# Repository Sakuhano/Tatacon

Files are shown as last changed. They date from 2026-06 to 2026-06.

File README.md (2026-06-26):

# What is a Tatacon?
A Tatacon is a controller that uses a drum and drumsticks as its input mechanism, its most commonly used for the hit Japanese arcade video game: Taiko No Tatsujin.
A tatacon usually consists of 2 main parts, a drum and an ebox. The drum is self explanatory, you hit it to make inputs on piezo sensors attached to it. These signals are then sent to the EBox, which consists of a microcontroller and other components to improve processing speed and reduce misinput. The main feature I added that I've never seen on a commercially available ebox is a screen. The screen has a settings function allowing you to adjust the individual and total sensitivities of each piezo on the controller. It also consists of a controller (completely digital) which you can use to not require an external controller to navigate the Nintendo switch. Both the screen and controller functions are powered by 2 different boards so as not to lose any processing time for the inputs and make the most accurate controller. This github is just design, as the printed case is not complete, along with other polish I would like to add when finishing this project. 

All CAD was made in Tinkercad, I moved them to Onshape for sharing

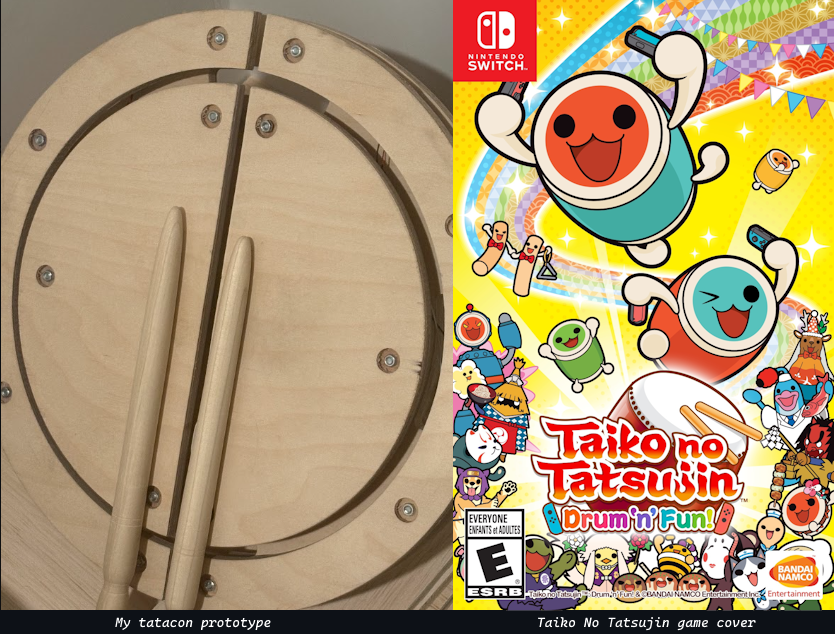
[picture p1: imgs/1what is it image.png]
Intro Screenshot


# Drum

I've split the section for the case and drum for ease of readability

## CAD and CNC

All the CNC machine files were based off openscad files by Moandor, these files are the standard shape used for almost all Tatacons, I made minimal edits for hole size (which turned out to be a mistake later however this was fixable with a drill)
I outsourced the CNC machine, and the woodshop generously offered the service at no-cost after hearing about my purpose. I then had to remove and sand each individual part from the large rectangle

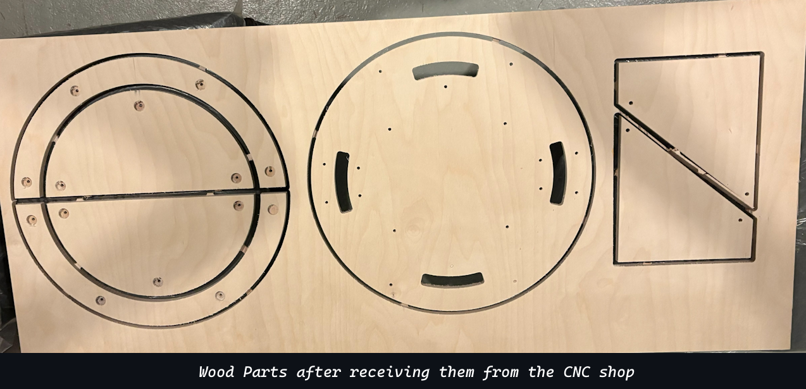
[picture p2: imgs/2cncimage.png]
CNC


Next, the CAD files were also based off the openscad files and were adapted for my specific size of wood and materials that I used.

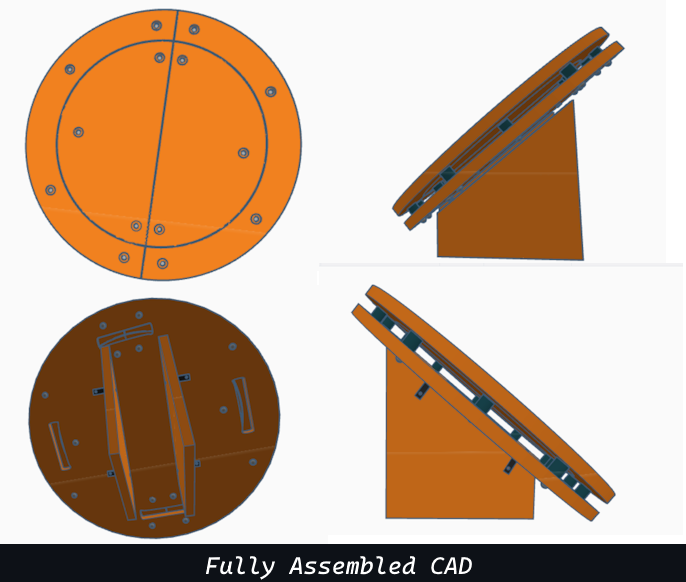
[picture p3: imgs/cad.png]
CAD


## Drumsticks

I made my own drumsticks as I have access to a lathe in school but it was made completely from scratch with no template, as such there is no design files for the drum stick. I just eyeballed them on the lathe. However, it is a replica of commonly available Taiko Bachi. Drumsticks are non-negotiable to use this product effectively.

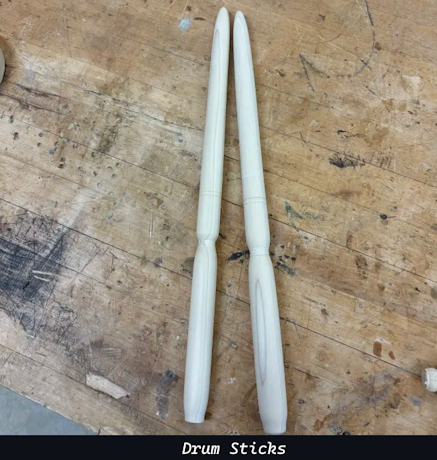
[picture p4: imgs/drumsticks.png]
DRMSTICK


## Drum Head (Skin)

Many projects like this buy official arcade skins imported from Japan, however those can range from 100-200 USD when factoring shipping. Due to this, I researched materials and found an effective substitute to be neoprene rubber. So using a strip and a large sheet, I constructed a drum head using superglue to bond the rubber. However, one issue is that the neoprene rubber releases a strong smell that fills a room, it can be mitigated by airing out the rubber however it still remains. Also, I use a towel over the head, as hitting the rubber with drumsticks quite hard tends to stain the sticks. Overall though, it works as quite a suitable substitute.

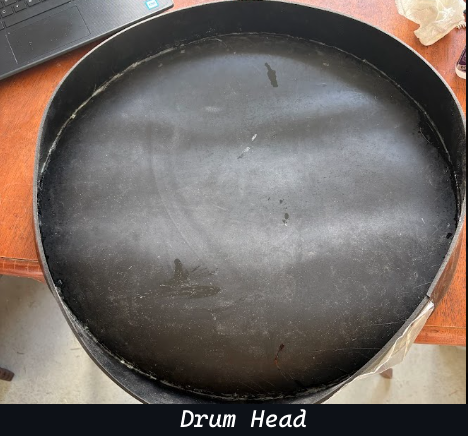
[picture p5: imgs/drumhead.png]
DRMHD


## Coding

To make the menu, I built off a lot of exisiting code, first I built a menu framework, basing it off code by upir, his code only had a menu framework and bitmap pixel art, however no features. I took his code and edited it to add my specific menus, run on a joystick for navigation as well as actually have features. The controller code is built off code from Luicat, which I took and allowed it to recieve inputs and changes from the menu. In these edits I allowed for serial communication between the boards so that one can interact with the other as well as actually send inputs to the Nintendo switch, making a successful digital controller and settings menu.

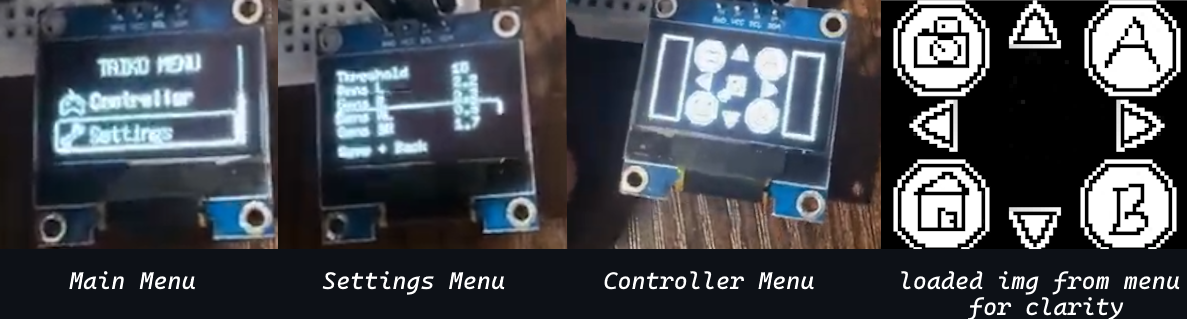
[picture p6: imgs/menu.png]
menus


## Pre Assembly

Before starting, there are a couple things to do to prepare. First it'll make life a lot easier if you solder extension wires on each piezo, however don't remove the wires that come preattached else you risk ruining the sensor. Then take each of these lengthened piezo sensors and electrical tape or glue them in the following locations to the top plate parts. There are successful labels on the 3d model, however they are difficult to see in this image.

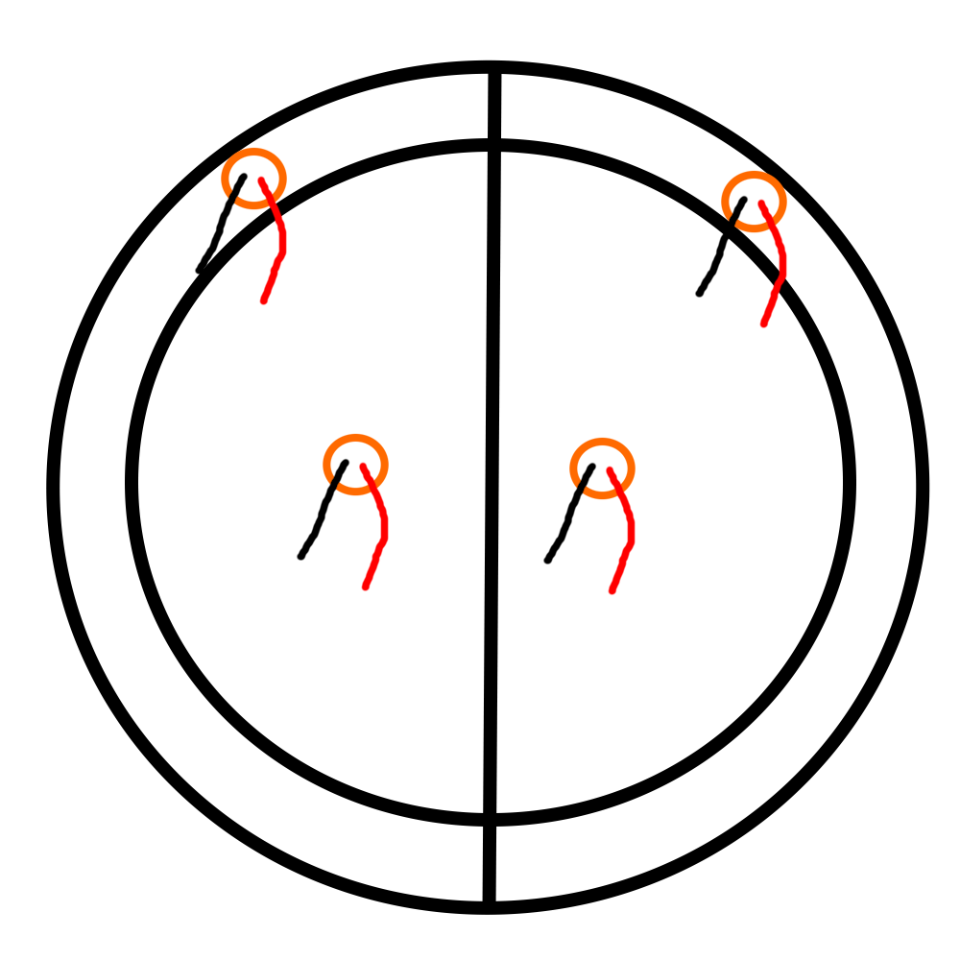
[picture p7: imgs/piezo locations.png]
piezos


## Drum Assembly

Assembly of this is quite easy once the parts are obtained, using the following items to hold things together
18x M5 bolts 
32x M5 thread nuts
46x washers (should be small and thin but size isn't super important)
soldering iron
electrical tape
piezos
wood pieces
corner brace
drill

Corner brace - note I included my specific one in the bom however, almost any can be used as I find it to be much better to just line up your support leg and measure where a hole using the brace has holes. This allows for much more part flexibility, and you just have to drill out the holes, and this is what I did for my brace.

To assemble, start with placing a washer on 14 of your M5 bolts, then take your bottom plate and place one of those 14 bolts in every single hole except for the 4 ones in the middle. it should look like this

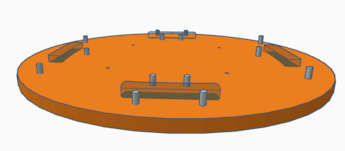
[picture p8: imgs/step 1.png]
Step 1


Now is the easiest time to place your support legs, Line up your corner brace(s) with your support legs and put a bolt through each of the 4 holes and add a nut on the opposite side from the bolt head and brace. Your supports shouldn’t move very much if at all.

Now, place a nut on each one of the bolts and screw it in fully, after this place each of your rubber dampers on the bolts and screw them in. now it should look something like this (support bolts not shown) , I've added a cross section of how it should look for each bolt

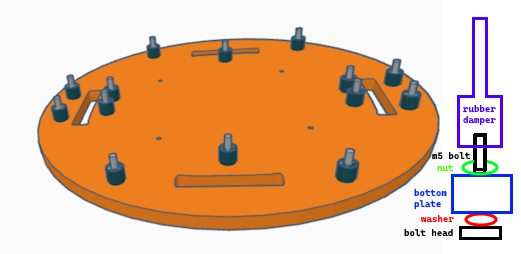
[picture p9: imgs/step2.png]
Step 2


Now place another washer on each, and place on each piece of the top plate, its easiest to thread the piezo wire extensions through the holes in the bottom plate now, then to finish off with adding a nut and tightening each bolt in fully. The image below is unfinished to make it easier to see. however the diagram on the right is complete

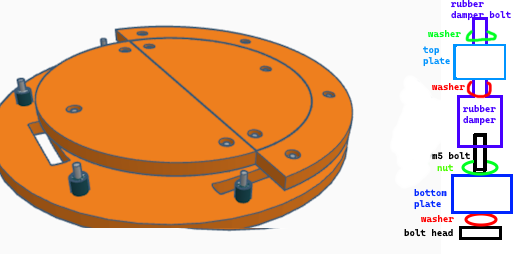
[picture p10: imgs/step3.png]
Step 3


Plug in your connectors attached to the piezo wires and you're good to go!

# Case/ebox
Originally, this was going to be a PCB, however after much research I thought making a case on the side to hold all my electronics would be much better. I've always liked how sim racing setups feel like stations rather than just accessories to the pc, I wanted the same vibe with this and with a large case on the side, it feels much more integrated into my gaming setup rather than being an accessory on the side. I'm a big fan of how it looks as well. 

## Code Flashing for Mega2560 R3

Take the leonardo code file and download all files inside. Open in arduino IDE and flash to the arduino mega2560 r3. 

## IDE preparation

Next follow the steps below, to use the code. These steps were taken from Luicats Github, as since my code is built off of his it requires this aswell
All credit goes to luicat for this, the required files are here: https://github.com/LuiCat/ArduinoTaikoController

### Modifications to Arduino IDE

Before starting Arduino IDE, to enable nintendo switch functionality, replace the following files with the ones provided in "setup" folder:

- `<your arduino installation path>/hardware/arduino/avr/libraries/HID/src/HID.h`
- `<your arduino installation path>/hardware/arduino/avr/libraries/HID/src/HID.cpp`

Then copy the text in board.txt in "setup" folder and append it to the following file:

- `<your arduino installation path>/hardware/arduino/avr/boards.txt`

If you've successfully done all the modifications above, you should be able to see the board called "Nintendo Switch Controller" next time you start Arduino IDE:

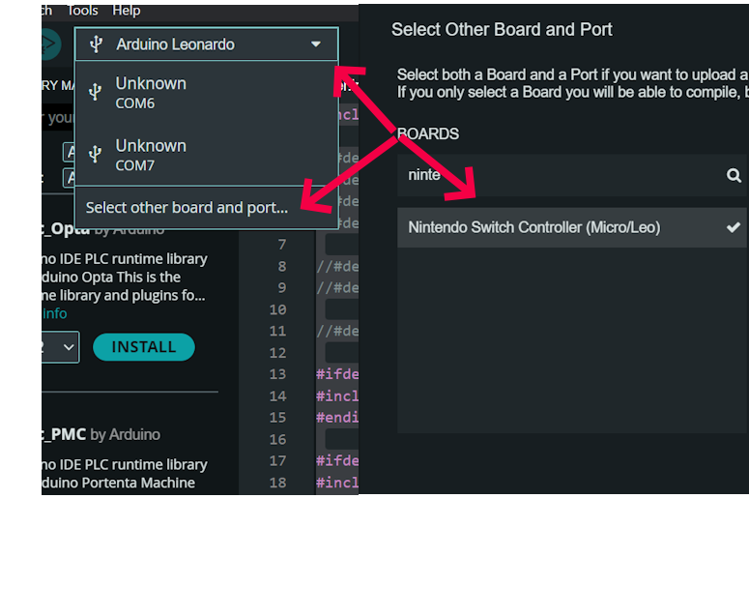
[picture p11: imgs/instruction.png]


Please select this board before uploading the code as this is essential for your Arduino Leonardo to be recognized by Nintendo Switch.

## Code Flashing for Leonardo

If the steps above have been followed you should be able to upload the code located in the leonardo code folder and just flash to the arduino.

## CAD

Using some part models I found online (credits in files) I added parts to my case to show what it would look like when fully done, below is the image, it has sections and text for easy assembly.

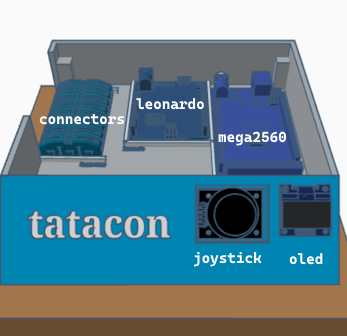
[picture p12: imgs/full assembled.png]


## Pre Assembly

Required materials:
Superglue
Neodymium Magnets
Plastic Screws and washers
Lever connectors
Arduinos
Ferrules
1m ohm resistor
dupont wires
db107 bridge rectifiers
soldering iron (optional)

First, after printing all the files, you want to take your magnets and glue them on the circle divots on the lid and the 4 lowered pillars in the case. 
Next, glue the joystick insert block on the case under the hole that corresponds with the joystick on the print. (check 3d file for reference). Take the Ferrules and place them on the wires coming out of the drum, differently colored in pairs so as to know which wire goes to which piezo.

## Base (optional)

requires
marker
drill
scrap wood
hammer

To add an extra element of flair you can make a base for your case, which makes it all the more cooler >:) this is totally optional though. To make one, you can use scrap wood and cut it to shape, then place your case over the wood in the spot you would like it to be. Mark the drill points by sticking a marker through the bolt holes for arduino. After drilling, hammer inserts into the holes. 

## Assembly

Now place all your components in their respective locations based on the image above as well as the labels placed on the board. Place your M3 bolts through the holes to lock all components into place. If you make a base, you can thread the bolts on the bottom through the m3 inserts Lock the components in with the washers. Glue 8 lever connectors in the spot that is labeled lever connector like the image above. Now you are ready to start wiring.

## Wiring

Wire everything according to the schematic below, its not necessary to use breadboards, as you can make your own splitter cables for ground by cutting dupont wires and soldering together. Go slow, and attach components to dupont wires for ease.

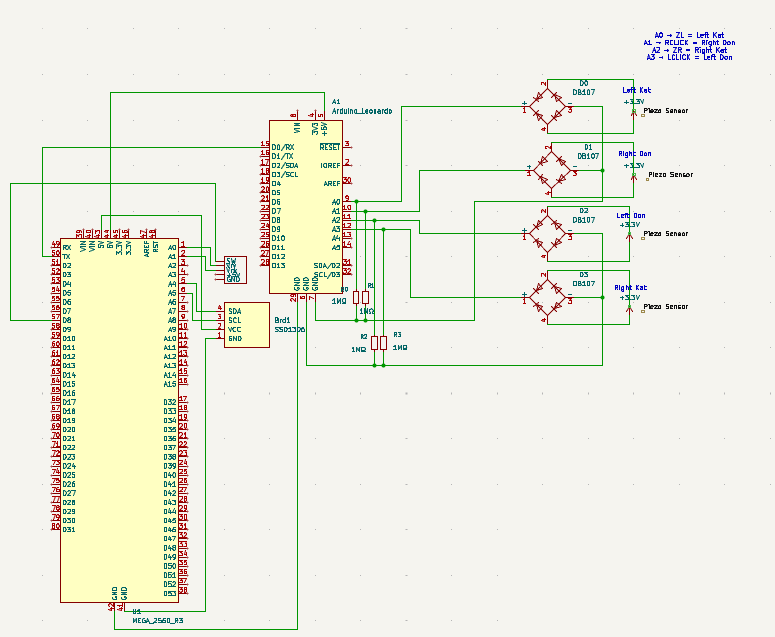
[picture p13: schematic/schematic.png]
schematic


After wiring everything together, plug the ferrules into the lever connects, close the lid and you're done!!!!

## Drumsticks

To make drumsticks I used a lathe and eyeballed some measurements using scrap wood for what I think the drumstick should be in thickness. However just searching up taiko no tatsujin bachi will help you find ones that work. Drumsticks are basically required for this as it makes much more precise inputs. However, I would more recommend just buying one if you don't have access or knowledge of using a lathe. They can go for as low as $10-$15 for a medium quality one.

## Why did I make this?

The idea for this project came to me when I saw an arcade game called Taiko No Tatsujin while abroad it uses a drum controller for inputs. I didn't give it much thought then, but when I got home. I really wanted to play it and found out there was an official controller available for purchase. It was called the Hori TaTacon. It cost about $70, so I was expecting a great product. But on first usage, I was disappointed. It required water bottles to keep it weighted so it didn't move, I had to hit it super hard for it to work and it was just janky. So I checked for alternatives online. I discovered numerous controllers available, however a decent one started at 200 for a small one and for a decent size one it went upwards of 500 or more. So I vowed to make my own. After doing some initial research over a year ago, I realized how much of a monumental task it was and gave up, but the want for one still lingered. And a year later, I found the motivation to start building again for Fallout. After many hours of work, that brings us to today.

## Acknowledgements

Luicat- provided the base controller code that was adapted
https://github.com/LuiCat/ArduinoTaikoController/tree/master

Newsham Woodshop in Aldan, PA for CNC machining my parts for no charge

upir on youtube for the base menu code and tutorial for menu building
https://www.youtube.com/watch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

Friends for helping and teaching me many things

My shop teacher for showing me how to use a lathe

Hack Club for providing the environment to build this

The Taiko no Tatsujin community for help

ShikyC - providing some wiring ideas and examples
https://github.com/ShikyC/Taiko-Drum-Controller-Arduino

Moandor for providing the base OPENSCAD files which I used to make CNCable files, as well as providing advice throughout this
https://github.com/moandor-y/taiko-no-tatsujin-drum

W3 schools for teaching me C++

and many others whose guides and articles I couldn't have made this project w/o

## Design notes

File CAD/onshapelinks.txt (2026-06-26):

onshape links

3d printed case stuff

case
https://cad.onshape.com/documents/54dbb6b467c79c1481cc51de/w/5ec1adc9ed4e6661e792b163/e/bbd9e8acfc5e05910346c073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

Joystick insert
https://cad.onshape.com/documents/fc0ff1775dbdd76d4b20aab2/w/3f028f6ef009c41b3ea4007a/e/76cd7d365b7bf1416ffd710e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

Lid
https://cad.onshape.com/documents/6eaeb32aaf644f3d68cbf503/w/1fe0b5226ccee433d61931fe

Drum Stuff 

full assembly
https://cad.onshape.com/documents/6aa020499e75e96b8eab69cc/w/65e557bf736931ccdf71789f/e/7f443d107fafc4eb4d13e204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

bottom plate
https://cad.onshape.com/documents/5576ca21738566e46db9488e/w/b4ec46c4cae221fd3d29429c/e/b8eab56c353da4d986eb8e67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

top plate inner circle half
https://cad.onshape.com/documents/6264209f9e15e6e33e3cf490/w/dd913410a18abddd75f68543/e/ff4a2ef36fbf7f71db56f856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

support leg
https://cad.onshape.com/documents/7e614a525852048ec9de92d2/w/fed911fc8de4cd6d258964b2/e/2d5b902312cc1db795a5a91f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

top plate outer ring half
https://cad.onshape.com/documents/2df3e2ba2070d28b6593318c/w/c982a54ffb2537adba425b43/e/677e48d9d90873e2fb1c649c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

long bolt
https://cad.onshape.com/documents/17738391c73abc8096c0120d/w/c15a20b6220537c8a73fae4a/e/787f6475aaf72aa3ffb1c559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

rubber damper insert
https://cad.onshape.com/documents/448b3b28842744ff81a8ea0b/w/0eaa3f8bf5ad5d896434f28e/e/ecefa9449a19118261a841f0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 

corner brace
https://cad.onshape.com/documents/f9e7ee72179795a1bbf91ffd/w/2ac4c80fcbbf8c5b16998179/e/1854f41f0b95239626bb5d1a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

drum head
https://cad.onshape.com/documents/2fa7758bc2087f84153a06a8/w/3eaaae4af81a9f6b6b8e88fe/e/0eb41013a2c1b161fea842c8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

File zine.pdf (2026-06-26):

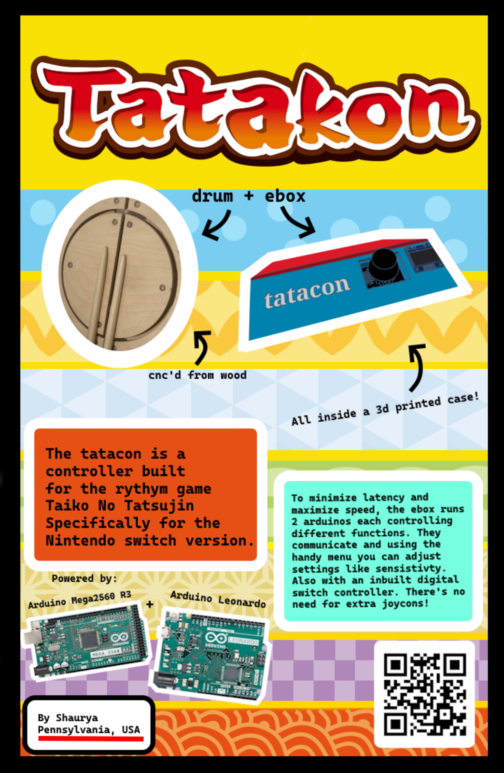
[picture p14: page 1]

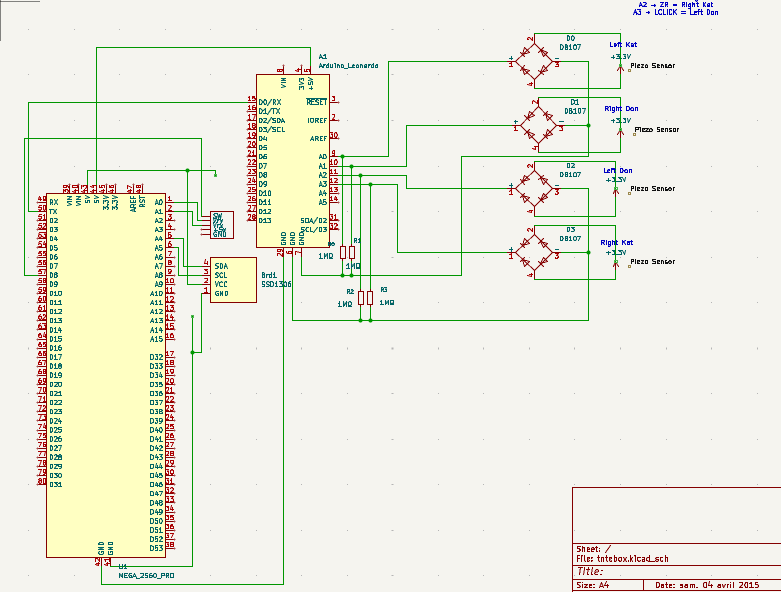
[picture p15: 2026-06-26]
imgs/Screenshot 2026-06-25 235739.png

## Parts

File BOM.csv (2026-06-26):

Item | Purpose | Source | Amount | Price | Subtotal | Total Spent (tax + shipping | Link
1/2 in. x 2 ft. x 4 ft. Sande Plywood | Material for the Drum | Home Depot | 1 | $27.26 |  |  | https://www.homedepot.com/p/ProWood-1-2-in-x-2-ft-x-4-ft-Sande-Plywood-Project-Panel-109068/202093791
Corner Brace | Joins stand of drum to drum pieces | Ace Hardware | 1 | $3.99 |  |  | https://www.acehardware.com/departments/hardware/angles-braces-and-brackets/braces/5021689
2mm x 6mm neodymium magnets | joins lid of case to case | Aliexpress | 1 | $4.63 |  |  | https://www.aliexpress.us/item/3256809168494688.html?mp=1&_randl_shipto=US
M5, 12mm vibration isolators | helps prevent other piezos from triggering when hitting the drum | AMAZON | 2 | $36.00 |  |  | https://www.amazon.com/dp/B07Z7GR4HW?ref=ppx_yo2ov_dt_b_fed_asin_title&th=1
Piezo Sensors (Guitar Pickups) | Houses the RP2040, connects to switch PCBs | Amazon | 1 | $6.99 |  |  | https://www.amazon.com/dp/B0DYNKK6B6?ref=ppx_yo2ov_dt_b_fed_asin_title
Assorted Nuts, Bolts, Washers | Joins everything together | Aliexpress | 1 | $14.97 |  |  | https://www.aliexpress.us/item/3256807011368573.html?mp=1
Neoprene Rubber Sheet 18x24" x 1/2'' | Sheet to cut drum head | Amazon | 1 | $34.19 |  |  | https://www.amazon.com/dp/B01CUQ51L4?ref=ppx_yo2ov_dt_b_fed_asin_title
Neoprene Rubber Ring 2" x 10' x 1/2' | Makes ring for drum head | Amazon | 1 | $12.00 |  |  | https://www.amazon.com/dp/B08LTJSTPT?ref=ppx_yo2ov_dt_b_fed_asin_title
Resistors 1MOHM | Used for the circut | Amazon | 1 | $4.99 |  |  | https://www.amazon.com/California-JOS-Tolerance-Resistor-Resistance/dp/B0BDKV4X96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
Jumper Cables | Used for the circut | Amazon | 1 | $6.98 |  |  | https://www.amazon.com/Elegoo-EL-CP-004-Multicolored-Breadboard-arduino/dp/B01EV70C78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
Arduino Leonardo | Used to control all components and circuts | Amazon | 1 | $23.80 |  |  | https://www.amazon.com/Arduino-org-A000057-Arduino-Leonardo-Headers/dp/B008A36R2Y?s=electronics
Lever Connectors | Used for the circut | Amazon | 1 | $4.99 |  |  | https://www.amazon.com/Electrical-Connectors-Assortment-Combination-Disconnect/dp/B0FLXBDNXM?s=industrial
Assorted Ferrules | attached to wires to connect them | Amazon | 1 | $4.99 |  |  | https://www.amazon.com/Terminals-Electrical-Connector-Insulated-Industrial/dp/B0FLX94V9H
Arduino Mega2560 R3 | Used to control the menu | Aliexpress | 1 | $3.99 |  |  | https://www.aliexpress.us/item/3256807774469671.html?curPageLogUid=RsXzqR9qEMZX
Elegoo White Filamente | Used as print mat | Amazon | 1 | $11.89 |  |  | https://www.amazon.com/ELEGOO-Filament-Dimensional-Accuracy-Compatible/dp/B0BM7WZPXJ
Assorted 22AWG wire | Used for connections | Amazon | 1 | $15.99 |  |  | https://www.amazon.com/TUOFENG-Hookup-Wires-6-Different-Colored/dp/B07TX6BX47?s=industrial
Electrical Tape | Sticking Piezos to wood and joining wires | Amazon | 1 | $2.98 |  |  | https://www.amazon.com/dp/B001AXD0EY?ref=ppx_yo2ov_dt_b_fed_asin_title&th=1
OLED Display SSD1306 | Used for menu system | Amazon | 1 | $9.99 |  |  | https://www.amazon.com/dp/B0FSRQG23K?ref=ppx_yo2ov_dt_b_fed_asin_title
Joystick | Used to control menu | Aliexpress | 1 | $5.78 |  |  | https://www.aliexpress.us/item/3256809168494688.html?mp=1&_randl_shipto=US
m3 wooden inserts | for inserting bolts into wood for case | Amazon | 1 | $5.79 |  |  | https://www.amazon.com/uxcell-Threaded-Stainless-Mechanical-Equipment/dp/B0DP2RYR2M
DB107 Bridge rectifier | used for better signal processing | Amazon | 1 | $5.99 |  |  | Tegg DB107 Bridge Rectifier 10PCS Electronic Silicon Diodes 1A 1000V 4-Pin Single Phase Diode Rectifier Bridge_AB: Amazon.com: Industrial & Scientific
Plastic bolts and nuts m3 | for attaching parts to the case | Amazon | 1 | $7.99 |  |  | https://www.amazon.com/QTEATAK-Plastic-Screws-Gasket-Assortment/dp/B0B17VVCMY
Hot Glue Gun | Used to apply hot glue | Owned | 1
Hot glue stick | Helps keep Piezos on wood | Owned | 1
Super Glue (Cyanoacrylate) | Helps join rubber ring to sheet | Owned | 1
Soldering Iron | Assembles the PCBs, can weld case to seal cracks | Owned | 1
Solder | Use with soldering iron for components | Owned | 1
Super Glue | Secures parts of the case to each other | Owned | 1
3d Printer | Used to print case | Owned | 1
CNC Mill | For Cutting Wood to shape | Outsourced (free) | 1
Sandpaper | For sanding wood | Owned | 1
Hand Saw | For cutting wood | Owned | 1
Wood Glue | For bonding wood | Owned | 1
Scrap Wood | Spare wood for base making | Owned | 1
Power Drill + bits | For drilling holes | Owned | 1
Marker | For marking points to drill | owned | 1
Hammer/mallet | For hammering in wooden inserts | Owned | 1
TOTAL COST USD |  |  |  |  | $256.17 | $271.54

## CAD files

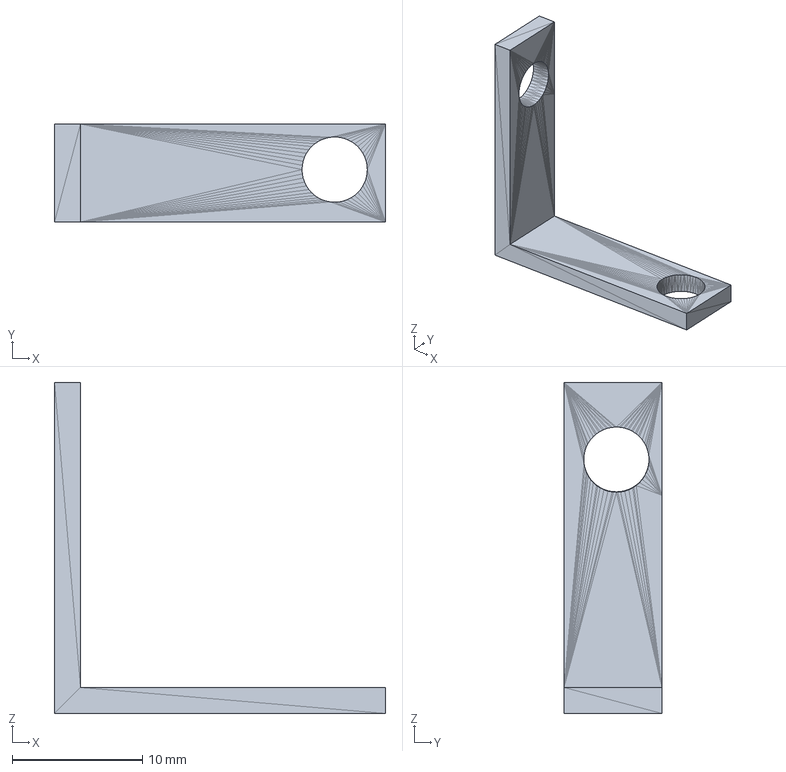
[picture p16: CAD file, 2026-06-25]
CAD/drum/assemblyparts/corner brace.step
25.4 x 7.52 x 25.4 mm

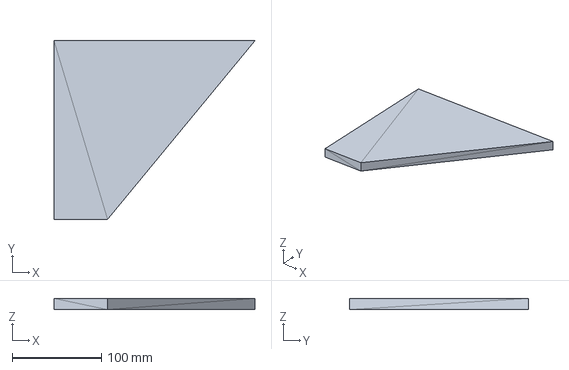
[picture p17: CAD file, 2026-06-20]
CAD/drum/bottom/support leg.step
225.0 x 200.0 x 12.7 mm

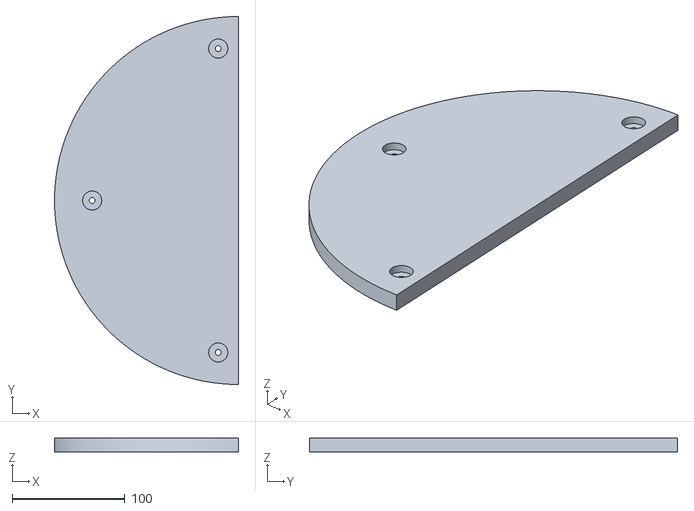
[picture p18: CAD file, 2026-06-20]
CAD/drum/top/top plate inner circle half.stl
163.5 x 327.0 x 12.7

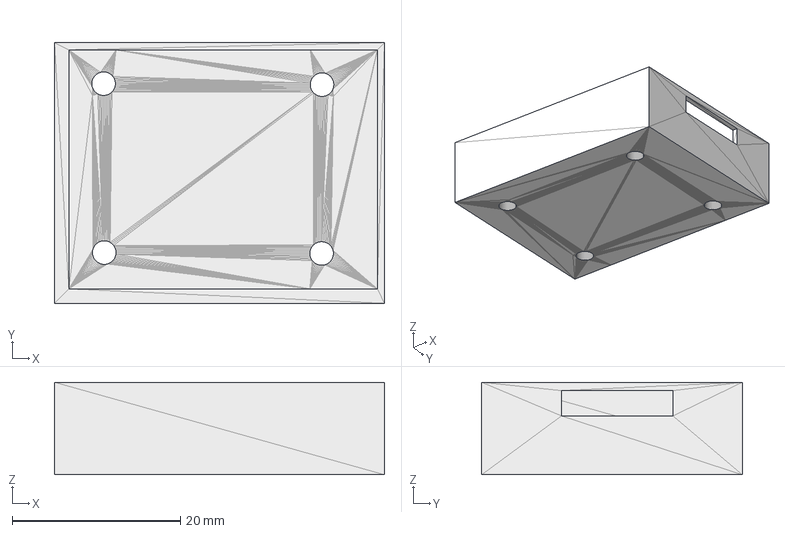
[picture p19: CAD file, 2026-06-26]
CAD/Case/joystick insert.step
39.2 x 31.0 x 11.0 mm

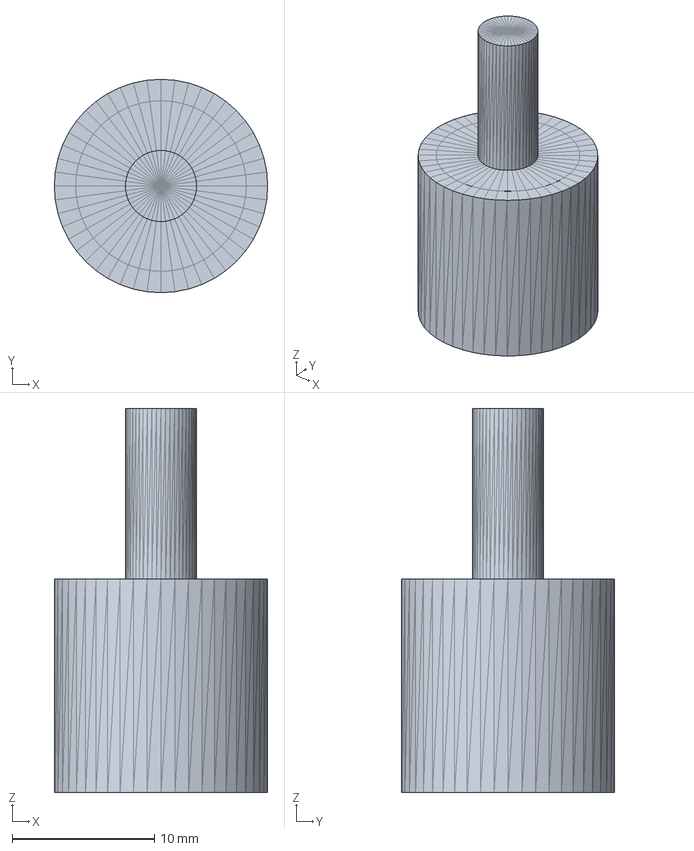
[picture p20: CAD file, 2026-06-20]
CAD/drum/assemblyparts/rubber insert.step
15.0 x 15.0 x 27.0 mm
STEP translator 7.5 1.1
STEP translator 7.5 1.2
STEP translator 7.5 1.3

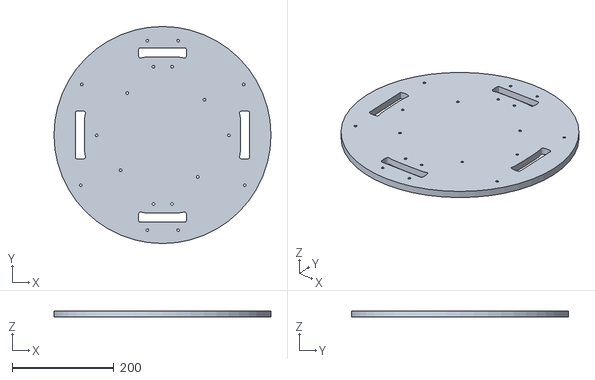
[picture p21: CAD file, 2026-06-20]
CAD/drum/bottom/bottom plate.stl
427.0 x 427.0 x 12.7

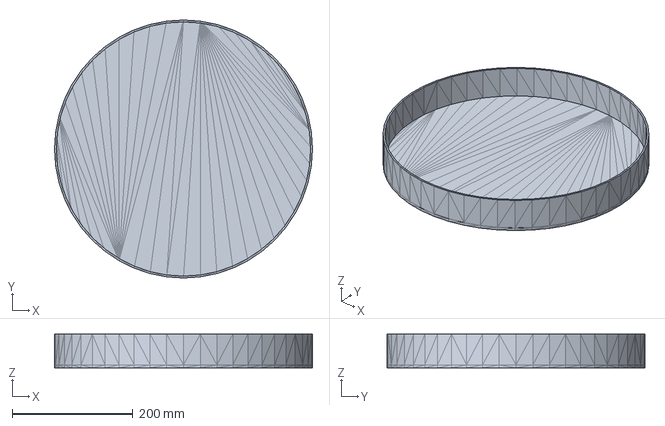
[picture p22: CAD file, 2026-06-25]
CAD/drum/drumhead.step
427.0 x 427.0 x 55.8 mm
STEP translator 7.5 1.1
STEP translator 7.5 1.2

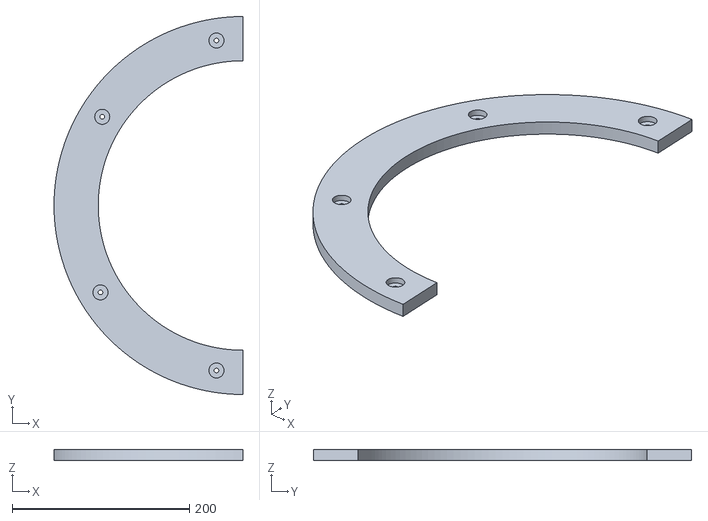
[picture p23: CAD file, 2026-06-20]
CAD/drum/top/top plate outer ring half.stl
213.5 x 427.0 x 12.7

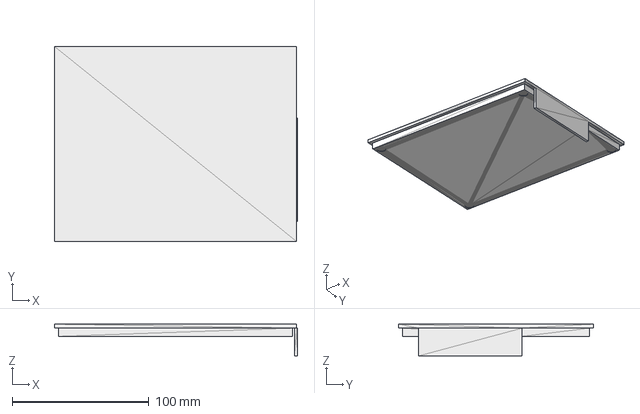
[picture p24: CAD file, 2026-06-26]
CAD/Case/roof.step
177.6 x 142.6 x 23.3 mm

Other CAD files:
CAD/drum/fully assembly.step
CAD/Case/case.step
CAD/drum/assemblyparts/long bolt.step
CAD/Case/case.stl
CAD/Case/joystick insert.stl
CAD/Case/roof.stl
CAD/drum/assemblyparts/corner brace.stl
CAD/drum/assemblyparts/long bolt.stl
CAD/drum/assemblyparts/rubber insert.stl
CAD/drum/bottom/support leg.stl
CAD/drum/drumhead.stl

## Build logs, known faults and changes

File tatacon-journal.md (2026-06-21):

# Tatacon — Journal Export

- Exported at: 2026-06-21T04:33:31Z
- Project ID: 2230
- Entries: 26

## Entry 1
- ID: 2982
- Author: shauryachutke
- Created At: 2026-04-19T23:28:44Z

### Content

Today, I worked on fixing issues and putting together my assembled parts of my Tatacon, my arduino code is very broken, but today I recieved all the parts from amazon. So i worked on testing, making a prototype and seeing what is wrong with my arduino code by testing on the actual videogame (hence the nintendo switch usage throughout the video) I managed to get it working for the first part but am currently having an issue where all piezos are sending the same output



101 minutes of work

### Recording Links

- https://www.youtube.com/watch?v=_0svMCqSPJo

## Entry 2
- ID: 3014
- Author: shauryachutke
- Created At: 2026-04-20T04:12:40Z

### Content

Today, I realized that my work yesterday was completely for naught, this made me a little sad, but it also gave me newfound motivation. You see, I realized I needed to change around my project quite a bit, yesterday was just a lot of hardware prototyping, fixing issues and general work for the actual controller with a lot of outside help, so much so that I realized this isn't my own project, infact im basically just following a tutorial no matter how much I change, regardless of what I do differently its basically the same general layout. So I realized I had to change things up a bit, instead of the making of the drum being my project, now I'm makiing my own custom EBOX, now you may ask. What the heck is an ebox? it sounds like a crappy knock off of a famous video game console. But it has nothing to do with that, an ebox for Taiko no tatsujin is what houses the electronics and circuitry for your actual taiko controller. Sounds simple enough right?, but its quite the opposite an ebox is the most integral component of your drum. They can be both simple and complex, it all depends on your code  you can add acessiories and all sorts of stuff, at its core its just the controller to send inputs to a drum but it can be so much more dpeending on what you do with it.
Today, I worked on doing some schematics, as its my first time doing kicad, so i was experimenting and learning with it while also modeling my prototype circuit. then I went into paint and modeled what i might want my PCB to look like.



### Recording Links

- https://lookout.hackclub.com/api/media/42abc607-094c-4bf3-9e1f-b150db092f2e/video.mp4

## Entry 3
- ID: 3156
- Author: shauryachutke
- Created At: 2026-04-21T04:01:38Z

### Content

Today was a lot of work on the base section of my drum, not the ebox. I finally got the parts I needed from amazon after ordering the wrong ones initiallty so my first drum was held up with tape, hopes, and dreams. But now I can finally use nuts and bolts >:). Except for the fact I forgot to get all the bolts I needed , so I know what I'm doing tommorow. Today was a bunch of building off of yesterday though, after going to the hardware store I bought some corner brackets so that was I could attach my supports to my actual backplate, however I did forget to record the corner bracket attachment and drilling which was a solid 45 minutes :(. Next I had to solder some of my piezos because over the weekend they broke, so I had to cut new wire that was actually long enough for my drum and didn't look like a complete mess, but I only had time for 2 before I had to go back to my class. So I'll continue that tommorow. Then after that was what I think the hardest part of today, making my drum head. I found no resources online on how to make my own, besides a material suggestion, so I decided to just wing it with the materials I had, I first cut out a rubber circle out of a large rubber sheet, I had to make my own compass tool to actually draw my circle too which took a while. Then cutting it was awful, it was really tough and I had to go quite slow, but I'm thankful I made no mistakes in that portion. Then I used superglue to glue my rubber strip around the circumference of my rubber circle, this was pretty bad and I think I breathed in too many superglue fumes, I also had to leave school midway and continue at home which kinda sucked because some of my strip kinda broke in the car ride home. But I got home and finished, this is the bad part though, I realized that by making my rubber circle bigger than my  backplate by about half an inch I had set myself up for failure. The rubber didn't fit snugly around the circle, meaning it was hard to attach and the rubber was also kinda of concaving into itself because it was originally rolled up. I'm still looking for a solution to this but for now I just added some strip on the inside to increase thickness. Then finally i went upstairs and put together my first prototype bywiring things things together, assembling the drum and 2 piezos annd testing on the game. 





### Recording Links

- https://lookout.hackclub.com/api/media/ccffe2c1-2404-4680-92b2-c149e2da0d29/video.mp4
- https://lookout.hackclub.com/api/media/3dda458f-5206-4c85-9353-068a0ff6e3a6/video.mp4
- https://lookout.hackclub.com/api/media/0b2eb833-0105-485f-adc3-582b54e839af/video.mp4
- https://lookout.hackclub.com/api/media/5d5f68c1-773c-4b8e-b661-58dd83a8d4fa/video.mp4
- https://lookout.hackclub.com/api/media/7d2a943c-879e-4513-b364-3fa3d0f45e43/video.mp4

## Entry 4
- ID: 3330
- Author: shauryachutke
- Created At: 2026-04-22T03:57:58Z

### Content

Overall, pretty decent day, I finally got some parts that I needed to finish the first prototype thst I tried yesterday. But after assembling and making a mess of wiring :( i made some mistakes so am trying to fix those however its working good. I thought raising my middle platforms would work well to offset the issues caused by the rubber head being to big but havent tried yet so  look out for that ig later today. I am proud that I was able to integrate the bridge capacitors I bought into a second breadboard I had and connected tomthe first so that way I could test the differences. 



### Recording Links

- https://lookout.hackclub.com/api/media/c13a05af-4416-48e3-889d-606fa0d4082d/video.mp4
- https://lookout.hackclub.com/api/media/f87230f3-f500-4840-a2d5-0550189cb48c/video.mp4

## Entry 5
- ID: 3340
- Author: shauryachutke
- Created At: 2026-04-22T05:00:45Z

### Content

Its a continuation of my other journal :D more than 3 hours done today, pretty proud of that. Besides that, the last 40 minutes were pretty cooked. I thought after assembling it was going to be easy breezy. It was not unfortunately "easy breezy". What followed after assembling was that it was partially working, 3/4 the buttons were sending inputs, 1 was sending the wrong input but overall I thought an easy fix. Then I looked at the wiring, then I got confused, there were no mistakes in wiring. Well, I thought there were but turns out I had it right all along (that did take up a lot of time though).I was extremely confused why 2 were sending the same input when connected to different inputs but oh well, my focus was on the part that sent no input. I thought I had a faulty piezo, but when exchanged same issue, I'm assuming its a sensitivity issue that I can adjust in code later but its quite annoying, secondly I somehow managed to stop all the buttons from working. So we started at about 50% succesful to 0% succesful, and it was 40 minutes of just frustration while listening to the same song on Taiko No tatsujin over and over, But such is the process of making something, it comes with good and it comes with bad and if I can't deal with failure or frustration or setback I'll never be able to make anything. Now, It's time to get my homework done. And I'm excited for a new tommorow.



### Recording Links

- https://lookout.hackclub.com/api/media/53ee500b-be87-4783-b174-0ac92afc0137/video.mp4
- https://lookout.hackclub.com/api/media/44baa002-443c-42e1-80e3-c0ae3a84ee1b/video.mp4

## Entry 6
- ID: 3497
- Author: shauryachutke
- Created At: 2026-04-23T03:34:00Z

### Content

After looking back through my schematics for some insights on how I could improve or fix my failing prototype, I came to the now obvious conclusion that it was impossible to look at. I could barely understand what was going on and it was pretty rough to look at. So I decided today to actually do a little Kicad research instead of going in completely blind and clean up my original schematic with labels and such. It's still a little messy and I don't understand a lot of stuff about Kicad. But, I'm overall pretty happy with how it turned out and I can't wait to start adapting this more my actual modifications and configurations I plan to add to make this project awesome :D. There's still a bunch I have to learn, but I'm definitely getting better and improving each day. I'm so excited to be part of hack club and can't wait for what else I do.


### Recording Links

- https://lookout.hackclub.com/api/media/263efa87-af05-4fab-9dff-b80a4bc98934/video.mp4
- https://lookout.hackclub.com/api/media/72e93248-44be-4fe7-a6b7-73067d9c52e0/video.mp4

## Entry 7
- ID: 3668
- Author: shauryachutke
- Created At: 2026-04-24T03:54:11Z

### Content

Today, quite the interesting day honestly. I didn't expect to get that much time in today and was planning on just trying to see what I did wrong in my build. However, after some careful thinking, I realized that the problems could be boiled down to a couple things. First, my sensitivity thresholds on my coding were too high, causing an input to not register, but then I thought about it further. Why the heck wasn't ANYTHING coming through the signal, no matter if I tapped the piezos directly or shuck the wood block it was attached to. I realized that it could also be a hardware issue, because my piezos looked likle they had been through 2 and a half wars. They were dirty, parts broken and overall just yikes. I assumed this didn't change much but I decided to give it a go on the multimeter and compare with some extra piezos I had recently ordered that I was hestiating on opening. Well the difference was SHOCKING to give a pun. The piezos I had been using barely got up to 1 volt max and that was only one. Most of them were capping around .5v or less. This was terrible, especially compared to the new ones which went up to 5 or 6 pretty easily. I knew that I had to make some changes, so I desoldered the wire on my other piezos, and at first I thought it would be good to directly attach them to the new piezos. However, that turned out to be a mistake, because it damaged the piezos and it became ineffective just like my other ones. So instead, I attached to the wires that were already soldered onto the piezos. I was having some trouble at first, both because my soldering iron was kinda crappy(broken tip), and my technique is pretty awful. But I realized that the broken shape of my iron was actually prefect for putting solder onto wires, and after that it all came out pretty well. It was a very long process, stripping wires with scissors and an exacto knife, wrapping, then hot gluing the solder pad on the piezo, and doing that 8 times took me a while. However, I'm very happy with how they turned out, and I can safely say that they look a lot better, so hopefully my problems are solved (Atleast hardware wise, and I can move on to tweaking the code and testing later tonight).



### Recording Links

- https://lookout.hackclub.com/api/media/729a4bf9-a3a2-48ff-89ab-94ec29e77307/video.mp4
- https://lookout.hackclub.com/api/media/ca6aeed5-0ada-4bb0-962c-d613f0298b58/video.mp4

## Entry 8
- ID: 3812
- Author: shauryachutke
- Created At: 2026-04-25T03:58:26Z

### Content

Yesterday during hardware testing, some of my piezos broke so I fixed them at school today as they have better soldering irons, and it was too late to set up my soldering stuff so I fixed it and made some backups in school today. When I got home, I wanted to fix the hardware issues from last night, (one of my inoputs was triggering randomly) so thats what I've been working on today. After changing the code base i was using i managed to get it somewhat working, not sure what the issue was though



### Recording Links

- https://lookout.hackclub.com/api/media/315d4cdf-79c5-45c9-81e3-faef4702b730/video.mp4
- https://lookout.hackclub.com/api/media/23c091d7-29ad-4b39-87d4-33272672aeee/video.mp4
- https://lookout.hackclub.com/api/media/0873297b-19f5-48ea-89d8-9550315f6bad/video.mp4

## Entry 9
- ID: 3994
- Author: shauryachutke
- Created At: 2026-04-26T03:57:55Z

### Content

Today I worked on C++, as I have no C++ skills to speak of and I want to be ready for Shenzen, as I have to learn to code for that. I also did more research on and  worked on my preliminary ebox design. My motivation to work on my drum has dipped a bit due to recent failure, and I'm writing this journal in advance of work as I don't wanna lose my streak. I've been out all day today and haven't had much to start but I'm basically planning out my schedule for the next hour rn. But i am starting to understand C++ a lot better which is really exciting!



### Recording Links

- https://lookout.hackclub.com/api/media/99682ca6-d3fb-4b64-9890-4fd37f135a32/video.mp4

## Entry 10
- ID: 4178
- Author: shauryachutke
- Created At: 2026-04-27T04:39:09Z

### Content

Today I'm working on continuing my W3 schools work, as well as working on shape for the first time, trying to learn and understand how to uses it to start my modeling, however I realized that I didn't understand it at all and I have forgotten all that I did in 7th grade with OnShape so I have to start relearning it from scratch. This is ok, and during my W3 schools work, I thought of a fun program I could make, and decided to start making it just as a little test to myself of what I've learned so far. It's just a thing that basically, it randomly adds or subtracts people from a room until a room has 6 people.



### Recording Links

- https://lookout.hackclub.com/api/media/4fc143d4-98a1-48f2-bbb4-cdaa89b319d0/video.mp4

## Entry 11
- ID: 4313
- Author: shauryachutke
- Created At: 2026-04-28T03:57:24Z

### Content

1. Today I'm gonna be continuing learning C++, as I feel I would be unprepared both for China, and making this project without having experience in C++. I made my first program yesterday, and I'm gonna be continuing with W3 Schools to try and get down the basics and everything else I might need for my project. I've also been looking into the parts I need and I'm gonna continue working on how the PCB would work,  as well as start to make my BOM for what I've done so far :D. Also I really don't understand the getline() function but its ok :D



### Recording Links

- https://lookout.hackclub.com/api/media/d57a67b7-0c9b-4069-9470-6e99870f6934/video.mp4

## Entry 12
- ID: 4438
- Author: shauryachutke
- Created At: 2026-04-29T03:37:57Z

### Content

Today, I was lowk locked and dialed for my project, I wanted to try to make up for my low time this weekend. Next week is finals week, so I'm super busy with studying and such. However, I'm trying my best to get work done and continue my streak. First, I worked on making a button input system that displays to an LCD. I literally have no idea how to do this, and I'm using my very  basic C++ experience and online guides to figure this out. This is an idea I'm experimenting with for my PCB, basically to count the hits , and statistics for each input of the controller, or add a menu like I saw in another controller online. Next, drumsticks but I'm lowk broke so I decided it would be good to use my schools lathe (which I have no experience with so I had to ask for some assistance from my teacher), using this I'm working on making some drumsticks, I've made most of one so far, and tomorrow I'm gonna start making the next one!



### Recording Links

- https://lookout.hackclub.com/api/media/93e37aa2-308a-4100-9f95-2dfb029f221f/video.mp4
- https://lookout.hackclub.com/api/media/1c564f4c-acf9-422a-959e-7456f8fd4bf9/video.mp4
- https://lookout.hackclub.com/api/media/c92b20ae-f7a7-46ef-a3ed-dcc13d37ea09/video.mp4
- https://lookout.hackclub.com/api/media/ce6bacd0-5a4f-421b-8d8c-826a86574fb5/video.mp4

## Entry 13
- ID: 4573
- Author: shauryachutke
- Created At: 2026-04-30T03:45:53Z

### Content

Today, I wasn't rexcording too much, as its hard to record while I'm moving and I like to move and walk around alot when I'm doing something like sanding (which is what I did today. But today, overall pretty chill. I finished my first drumstick which I'm very happy about, then I have to set up my second drum stick for the lathe tommorow, (which is what I'm gonna do). Then, after that I was pretty busy and out for most of the day, but I got home and I wanted to try working on my button input system for the LCD board. Basically, it jsut displays total of each hit and makes it easier for both debug and I want it as a feature on my final board I'm gonna put into kicad. But my lack of coding skills really holds me back, so I think I want to work on more W3 schools, cause I literally have to search up how to do everything, and my syntax still sucks butt. Anyways, I got a little frustrated and decided to start work on my BOM which actually looks pretty okay. I used my amazon list for prices and such. Tommorow, gonna do work on the lathe, maybe also make a cool laser design for the drumsticks!


!

### Recording Links

- https://lookout.hackclub.com/api/media/184b3480-5b6f-489c-9e20-35e204452392/video.mp4
- https://lookout.hackclub.com/api/media/44a9c510-590d-4342-bfc0-a7aa14a963f0/video.mp4

## Entry 14
- ID: 4713
- Author: shauryachutke
- Created At: 2026-05-01T03:56:41Z

### Content

Today, overall a pretty relaxing day. In school, I started making my second drumstick and overall it's turning out pretty okay. It's a little tough to match the dimensions and design to the other one but I'm doing my best and I think its coming out well. After I got home, I started working on my Zine page, I have a vision and just worked on one of the text elements in my poster for today.



### Recording Links

- https://lookout.hackclub.com/api/media/0ac6040e-be17-4c7a-9c68-acf11e7f9767/video.mp4
- https://lookout.hackclub.com/api/media/6fac2768-55d8-404b-880b-0b2f0c167f88/video.mp4
- https://lookout.hackclub.com/api/media/fe38342d-9061-4a0c-8e51-a30906f66285/video.mp4

## Entry 15
- ID: 4848
- Author: shauryachutke
- Created At: 2026-05-02T03:04:58Z

### Content

Ok, so while continuing to make my drumstick in school today. I accidentally closed a door to pick something up that was right in front of my video set up. Because of this, my recording of about 29 minutes named (failed timelapse) only has about 21 minutes of work shown even though I was working for the full 30. To make up for this I did, I did about 10-15 minutes of hardware work after I got home from school that I didn't add to the journal. I apologize, but I didn't want to lose my 20 or so min that were visible. Especially in my finals week where I don't have very much spare time :(. I also just did some zine work.



### Recording Links

- https://lookout.hackclub.com/api/media/e89f6350-cee5-47fc-a66b-533a123c117f/video.mp4
- https://lookout.hackclub.com/api/media/5e90f6a6-5c43-403d-897a-0ee9466edf54/video.mp4
- https://lookout.hackclub.com/api/media/95e120bd-d5b0-4ef0-9e65-5fefa86e3e80/video.mp4

## Entry 16
- ID: 4850
- Author: shauryachutke
- Created At: 2026-05-02T03:07:58Z

### Content

Accidentally added the wrong image to my last journal, so I changed it to the drumsticks I actually wanted to add

Screenshot 2026-04-30 235124.png

### Recording Links

- https://lookout.hackclub.com/api/media/f6740db4-2f11-4771-bdd4-9db022b55641/video.mp4

## Entry 17
- ID: 5213
- Author: shauryachutke
- Created At: 2026-05-03T03:45:18Z

### Content

Today, I did some more work on my zine page, and I realized I hated how it looked in canva, so I started from scratch in paint.net which I'm more familiar with.  I'm taking inspiration from the taiko no tatsujin rythym festival art page, and using elements from that in my design. It's coming along well so far, thought I've only added a couple small things. I think tommorow I might work on moddeling, kicad, w3schoools or just continue the ZINE. Overall, I'm happy with my progress so far but I'm a little worried about that 60 hour req as I feel like I'm close to done but also so far away.



### Recording Links

- https://lookout.hackclub.com/api/media/e40141b1-5cbe-4127-87ba-d9c4a6d98b49/video.mp4

## Entry 18
- ID: 5376
- Author: shauryachutke
- Created At: 2026-05-04T03:45:33Z

### Content

Honestly, not too much going on today and I considered not even posting a journal cause I was so locked into microeconomics (final EXAM TOMMOROW :( however I decided my zine page needed work, and i spent most of the time working on this one star pattern I wanted to add that I could NOT seem to get right, still unfinished but oh well thats for a different day
Screenshot 2026-05-03 234307.png

### Recording Links

- https://lookout.hackclub.com/api/media/37c62ac9-1540-4db2-9167-14de95476718/video.mp4

## Entry 19
- ID: 5547
- Author: shauryachutke
- Created At: 2026-05-05T03:58:21Z

### Content

Today, It was definitely a struggle to open up fallout and start recording, Normally I would be all over it but I have my Gov final tommorow so finding the justification to open up and record was a bit tough. However, I thought about what I worked on earlier that day, which was just trying to code and understand the extra features for my ebox. After about 15-20 minutes I forgot to record, I realized the code and syntax was hard for me to understnad in every regard so I decided today was a great day to finally lock back into w3 schools and catch up what I had been slacking on. Thats what I did, and it took me a while today and my progress def slowed as it took me longer to understand each part, I even had to consult the big GPT for one part. But overall, I got through it
Captura de pantalla 2026-05-05 055342.png

### Recording Links

- https://lookout.hackclub.com/api/media/f7ba3b4b-471c-416e-a4b7-5a0e9bae02d1/video.mp4

## Entry 20
- ID: 5836
- Author: shauryachutke
- Created At: 2026-05-07T03:36:01Z

### Content

Today, I worked on the LCD system for the board I want to design, however I ran into some problems. My main issue is that I have no idea what I'm doing wrong, in my code it should in theory display an output from 0-1023, with a 0 when the switch is closed and a 1023 when it's open. However both of my switches that are connected to the same circut output different things, and their value doesnt even change when I open and close the switch. I want to work more on it, but I have finals to lock in for :(. However, i think my work with C++ on W3 schools is amazing. I feel like I'm understanding more, and even the little I can do right now I don't think I would be able to without going through those tutorials.



### Recording Links

- https://lookout.hackclub.com/api/media/771dd657-4c72-4d2b-b10e-f1e71ad5e1f9/video.mp4

## Entry 21
- ID: 6033
- Author: shauryachutke
- Created At: 2026-05-08T03:52:16Z

### Content

Ok so I geniunely don't even know what to say. I didn't expect to make much progress, BUT I got my button mechanism actually working and I'm so happy. It's super wonkly, and I'm sure there's way better ways to do edge detection and this feels processor intensive but idc. I'll improve later I'm just happy to have progress!!!

Screenshot 2026-05-07 235041.png

### Recording Links

- https://lookout.hackclub.com/api/media/715819b2-d992-405d-b843-ea5ef8e0b2bd/video.mp4
- https://lookout.hackclub.com/api/media/757a9f24-9cc9-4414-9fc6-7bce6b48376d/video.mp4
- https://lookout.hackclub.com/api/media/15c71ec8-8c37-4a51-ba94-5183fb5ca590/video.mp4

## Entry 22
- ID: 6196
- Author: shauryachutke
- Created At: 2026-05-09T03:44:02Z

### Content

Today, I was a bit locked in ngl. After finishing a rudimentary version of edge detection yesterday, Today I wanted to work on the actual features that those kinds of things would be implemented into. Specifically, the menu features that go along with it. However, my lack of experience strikes again, as it took me like half the time to download the necessary programs. And the other half of time was spent trying to understand the menu example code that I still have no idea about.
Screenshot 2026-05-08 233912.png

### Recording Links

- https://lookout.hackclub.com/api/media/f1821b11-0cf9-4f31-8d8f-8a79acaf59eb/video.mp4

## Entry 23
- ID: 6373
- Author: shauryachutke
- Created At: 2026-05-10T03:38:55Z

### Content

Today, I worked on learning more about how to make the menu. It's so much more difficult than I expected and I took almost the whole time understanding the code. But now I think I'm startuing to get the hang of it. I tried writing some code at the end but it's still a little confusing just trying to learn as much as I can to do this.
Screenshot 2026-05-09 233515.png

### Recording Links

- https://lookout.hackclub.com/api/media/d45f24bc-2276-41d1-a2fe-5a7a093dcbb2/video.mp4

## Entry 24
- ID: 6708
- Author: shauryachutke
- Created At: 2026-05-12T03:55:20Z

### Content

So I started off designing my fritzing schematic for my circut, just prototyping my initial design to see what might work. But I realized something, my connector would be kinda cooked. So, I did some research about how similar products to what I'm trying to make do their connections. I came across the idea of a hexagon connector. I didn't see anything on the board, but it gave me the idea to go and design one I could use. So I hopped into tinkercad(rudimentary I know, I need to learn onshape). But I started making the preliminary design for that connector, and I also researched ideas of connecting my piezos wires to that connector in a way that would hold up. I think screw joints or something would be weird but I'll have to figure it out.
Screenshot 2026-05-11 235202.png

### Recording Links

- https://lookout.hackclub.com/api/media/7722c4c9-fb16-4f57-b0c0-e58f2c0ad1e7/video.mp4

## Entry 25
- ID: 6870
- Author: shauryachutke
- Created At: 2026-05-13T03:48:46Z

### Content

Today, I did some research and sent out an email to someone who had given me advice on my prototype drum. They've designed the specific component I need before and I asked for some advice about my specific circut. I'll do some prototype testing later, but I thought I would also just ask for expert advice. if I have it available. Then I worked on kicad and adding my specific parts I wanted into kicad. Adding onto my base circut, and learning how to wire a rotary encoder (still no idea) :(. I've recently only been doing 1 hour journals because of finals but after thursday I'll have the free time to journal more
Screenshot 2026-05-12 234832.png

### Recording Links

- https://lookout.hackclub.com/api/media/d715870b-0037-4363-9d05-57cd3cf8c481/video.mp4

## Entry 26
- ID: 15772
- Author: shauryachutke
- Created At: 2026-06-20T20:37:22Z

### Content

This is my longest journal yet because I just rushed through everything I had left to do. 

Lets go through it, first I started looking for options to make my menu and came across a nice video which detailed a style of menu i was interested in, this turned out to be a lifesaver because it was much easier to understand than the menu i was using before. This menu made life so much easier for me, I managed to figure out a ton of stuff quite quickly because the video also helped to explain everything. So using that video as a guide I  made a frame work of my menu, making pixel art and such for all the various sections (I really loved how it looked). Then I started coding the functionality for everything, I made an intiail scrollable menu based off the starting menu code. Then I thought it would be way easier to use a joystick for inputs instead of something like 3 buttons. So I switched my code over to a joystick based system. So after this, I made a library to control everyhing joystick based which allowed me to easily add functions I needed. Then I uploaaded this to the arduino library manager. because makes it easier to put into the emulator and make code edits while not on my current computer( this comes in handy later), Then afterwards, I worked on doing pixel art for the next section, the emulator controller. My friend offered me a suggestion for menu type, instead of a button selector and moving around the joystick, why not make a radial menu that you just have to pull the joystick in the direction of your input. And so, I switched my pixel art over to that, which was kind of torturous but oh well. I finished that code, then managed to finally get it working on my emulator woooo hoooo. The bitmaps were broken for a while but it all turned out okay so we ball, turns out the video mentioned the parameters for the drawing function wrong so I had it incorrect the whole time. Anyways, after fixing that, I realized time was running out, so I went back to my github page, and looked at what I needed. I went back to my initial phase of planning and saw what I did, so I made my CAD models, which were based off dxf files which were actually edits of files I found from someone online, now the reason I used the ones online is because after my research, that shape is the commonly used framework for all tatacons (drum controllers). So I could just base my CAD off these openscad files, while adding the dimensions and different parts I used. I also finished my bom using another bom as a template. Today, I have to go to 2 grad parties taking up my whole day, however after working throughout the night I still wasnt done, so I texted a friend and was able to arrange to work on his laptop, so I transferred my code over, and continued to work on it. I'm actually writing the journal from his house now, but I have to leave soon to go to the next party, where I'll continue to do work. I still have a bunch of coding and assembly to do. Hoping to god this all works out and I finish in time :(. Love you fallout, you taught me so much. This is probably my final journal b4 my submission. Peace out!
Screenshot 2026-06-20 163645.png

### Recording Links

- https://lookout.hackclub.com/api/media/3966dfbb-1aa1-4cf9-af7c-f294c0cd334d/video.mp4
- https://lookout.hackclub.com/api/media/3b7404c8-32a0-4b31-ac75-85a17a7b3553/video.mp4
- https://lookout.hackclub.com/api/media/7d155581-db5a-4806-b730-779e381ce028/video.mp4
- https://lookout.hackclub.com/api/media/8e34ece1-8696-404a-a1f6-df32bd877aba/video.mp4
- https://lookout.hackclub.com/api/media/870d5f5f-9dfb-45a1-8591-ca4ab7723179/video.mp4
- https://lookout.hackclub.com/api/media/3a7534f6-e0b2-45a0-b5e4-00b709a0c44b/video.mp4
- https://lookout.hackclub.com/api/media/7d7e07a4-8e51-40ac-894e-9bca3e5d8e35/video.mp4
- https://lookout.hackclub.com/api/media/85515103-cda3-4cb4-a03a-0e9a23bb4de9/video.mp4
- https://lookout.hackclub.com/api/media/fb9f17ee-8698-4a79-9f01-0502368a61d8/video.mp4

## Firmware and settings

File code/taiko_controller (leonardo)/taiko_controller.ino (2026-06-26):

#include "AnalogReadNow.h"

#define ENABLE_NS_JOYSTICK

#ifdef ENABLE_KEYBOARD
#include <Keyboard.h>
#endif

#ifdef ENABLE_NS_JOYSTICK
#include "Joystick.h"
const int led_pin[4] = {8, 9, 10, 11};
const int sensor_button[4] = {SWITCH_BTN_ZL, SWITCH_BTN_LCLICK, SWITCH_BTN_RCLICK, SWITCH_BTN_ZR};
#endif

#ifdef HAS_BUTTONS
int button_state[16] = {0, 0, 0, 0, 0, 0, 0, 0, 0, 0, 0, 0, 0, 0, 0, 0};
int button_cd[16] = {0, 0, 0, 0, 0, 0, 0, 0, 0, 0, 0, 0, 0, 0, 0, 0};
#ifdef ENABLE_KEYBOARD
const int button_key[16] = {
  KEY_UP_ARROW, KEY_RIGHT_ARROW, KEY_DOWN_ARROW, KEY_LEFT_ARROW,
  'k', 'j', 'f', 'd',
  KEY_PAGE_DOWN, KEY_PAGE_UP, KEY_ESC, ' ',
  KEY_F1, 'q', 0 , 0
};
#endif
#ifdef ENABLE_NS_JOYSTICK
const int button[16] = {
  0 , 0 , 0 , 0 ,
  SWITCH_BTN_X, SWITCH_BTN_A, SWITCH_BTN_B, SWITCH_BTN_Y,
  SWITCH_BTN_L, SWITCH_BTN_R, SWITCH_BTN_SELECT, SWITCH_BTN_START,
  SWITCH_BTN_CAPTURE, SWITCH_BTN_HOME, 0 , 0
};
const int hat_mapping[16] = {
  SWITCH_HAT_CENTER, SWITCH_HAT_U, SWITCH_HAT_R, SWITCH_HAT_UR,
  SWITCH_HAT_D, SWITCH_HAT_CENTER, SWITCH_HAT_DR, SWITCH_HAT_R,
  SWITCH_HAT_L, SWITCH_HAT_UL, SWITCH_HAT_CENTER, SWITCH_HAT_U,
  SWITCH_HAT_DL, SWITCH_HAT_L, SWITCH_HAT_D, SWITCH_HAT_CENTER,
};
#endif
#endif

int min_threshold = 15;
float sens[4] = {1.0, 1.0, 1.0, 1.0};

const long cd_length = 10000;
const float k_threshold = 1.5;
const float k_decay = 0.97;

const int pin[4] = {A0, A3, A1, A2};
const int key[4] = {'d', 'f', 'j', 'k'};

const int key_next[4] = {3, 2, 0, 1};

const long cd_stageselect = 200000;

bool stageselect = false;
bool stageresult = false;

float threshold = 20;
int raw[4] = {0, 0, 0, 0};
float level[4] = {0, 0, 0, 0};
long cd[4] = {0, 0, 0, 0};
bool down[4] = {false, false, false, false};
#ifdef ENABLE_NS_JOYSTICK
uint8_t down_count[4] = {0, 0, 0, 0};
#endif

typedef unsigned long time_t;
time_t t0 = 0;
time_t dt = 0, sdt = 0;

void sample() {
  int prev[4] = {raw[0], raw[1], raw[2], raw[3]};
  raw[0] = analogRead(pin[0]);
  raw[1] = analogRead(pin[1]);
  raw[2] = analogRead(pin[2]);
  raw[3] = analogRead(pin[3]);
  for (int i=0; i<4; ++i)
    level[i] = abs(raw[i] - prev[i]) * sens[i];
}

void sampleSingle(int i) {
  int prev = raw[i];
  raw[i] = analogReadNow();
  level[i] = abs(raw[i] - prev) * sens[i];
  analogSwitchPin(pin[key_next[i]]);
}

void setup() {
  analogReference(DEFAULT);
  analogSwitchPin(pin[0]);
  pinMode(LED_BUILTIN, OUTPUT);
  digitalWrite(LED_BUILTIN, LOW);
#ifdef ENABLE_NS_JOYSTICK
  for (int i = 0; i < 8; ++i) pinMode(i, INPUT_PULLUP);
  for (int i = 0; i < 4; ++i) {  digitalWrite(led_pin[i], HIGH); pinMode(led_pin[i], OUTPUT); }
#endif
#ifdef ENABLE_KEYBOARD
  Keyboard.begin();
#endif
  t0 = micros();
  Serial.begin(9600);

  Serial1.begin(9600);
}

void parseSerial() {

  static char command = -1;
  if (Serial.available() > 0) {
    char c = Serial.read();
    if (command == -1)
      command = c;
    else {
      switch (command) {
      case 'C':
        Serial.write('C');
        Serial.write(c);
        Serial.flush();
        break;
      case 'S':
        stageselect = (c == '1');
        digitalWrite(LED_BUILTIN, stageselect ? HIGH : LOW);
        break;
      case 'R':
        stageresult = (c == '1');
        digitalWrite(LED_BUILTIN, stageresult ? HIGH : LOW);
        break;
      }
      command = -1;
    }
  }

  static char s1_command = -1;
  static int  s1_sens_idx = -1;

  while (Serial1.available() > 0) {
    char c = Serial1.read();

    if (s1_command == 'W' && s1_sens_idx == -1) {
      s1_sens_idx = (int)(unsigned char)c;
      continue;
    }

    if (s1_command == -1) {
      s1_command = c;
      continue;
    }

    switch (s1_command) {

      case 'V': {
        #ifdef ENABLE_NS_JOYSTICK
        switch (c) {
          case 'A': Joystick.Button |= SWITCH_BTN_A;       break;
          case 'B': Joystick.Button |= SWITCH_BTN_B;       break;
          case 'H': Joystick.Button |= SWITCH_BTN_HOME;    break;
          case 'C': Joystick.Button |= SWITCH_BTN_CAPTURE; break;
          case 'U': Joystick.HAT = SWITCH_HAT_U;           break;
          case 'D': Joystick.HAT = SWITCH_HAT_D;           break;
          case 'L': Joystick.HAT = SWITCH_HAT_L;           break;
          case 'R': Joystick.HAT = SWITCH_HAT_R;           break;
        }
        Joystick.sendState();
        delay(25);
        Joystick.Button = SWITCH_BTN_NONE;
        Joystick.HAT = SWITCH_HAT_CENTER;
        Joystick.sendState();
        #endif
        break;
      }

      case 'T': {

        int val = (int)(unsigned char)c;
        if (val >= 1 && val <= 255) min_threshold = val;
        break;
      }

      case 'W': {

        if (s1_sens_idx >= 0 && s1_sens_idx <= 3) {
          int val = (int)(unsigned char)c;
          if (val >= 1 && val <= 50) {
            sens[s1_sens_idx] = val / 10.0f;
          }
        }
        s1_sens_idx = -1;
        break;
      }
    }

    s1_command = -1;
  }
}

void loop_test() {
  sampleSingle(0);
  Serial.print(level[0]);
  Serial.print("\t");
  delayMicroseconds(500);
  sampleSingle(1);
  Serial.print(level[1]);
  Serial.print("\t");
  delayMicroseconds(500);
  sampleSingle(2);
  Serial.print(level[2]);
  Serial.print("\t");
  delayMicroseconds(500);
  sampleSingle(3);
  Serial.print(level[3]);
  Serial.println();
  delayMicroseconds(500);
}

void loop_test2() {
  Serial.print(analogRead(pin[0]));
  Serial.print("\t");
  delayMicroseconds(500);
  Serial.print(analogRead(pin[1]));
  Serial.print("\t");
  delayMicroseconds(500);
  Serial.print(analogRead(pin[2]));
  Serial.print("\t");
  delayMicroseconds(500);
  Serial.print(analogRead(pin[3]));
  Serial.println();
  delayMicroseconds(500);
}

void loop() {

  static int si = 0;

  parseSerial();

  time_t t1 = micros();
  dt = t1 - t0;
  sdt += dt;
  t0 = t1;

  float prev_level = level[si];
  sampleSingle(si);
  float new_level = level[si];
  level[si] = (level[si] + prev_level * 2) / 3;

  threshold *= k_decay;

  for (int i = 0; i != 4; ++i) {
    if (cd[i] > 0) {
      cd[i] -= dt;
      if (cd[i] <= 0) {
        cd[i] = 0;
        if (down[i]) {
#ifdef ENABLE_KEYBOARD
          Keyboard.release(stageresult ? KEY_ESC : key[i]);
#endif
          down[i] = false;
        }
      }
    }
  }

  int i_max = 0;
  int level_max = 0;

  for (int i = 0; i != 4; ++i) {
    if (level[i] > level_max && level[i] > threshold) {
      level_max = level[i];
      i_max = i;
    }
  }

  if (i_max == si && level_max >= min_threshold) {
    if (cd[i_max] == 0) {
      if (!down[i_max]) {
#ifdef DEBUG_DATA
        Serial.print(level[0], 1);
        Serial.print("\t");
        Serial.print(level[1], 1);
        Serial.print("\t");
        Serial.print(level[2], 1);
        Serial.print("\t");
        Serial.print(level[3], 1);
        Serial.print("\n");
#endif
#ifdef ENABLE_KEYBOARD
        if (stageresult) {
          Keyboard.press(KEY_ESC);
        } else {
          Keyboard.press(key[i_max]);
        }
#endif
        down[i_max] = true;
#ifdef ENABLE_NS_JOYSTICK
        if (down_count[i_max] <= 2) down_count[i_max] += 2;
#endif
      }
      for (int i = 0; i != 4; ++i)
        cd[i] = cd_length;
#ifdef ENABLE_KEYBOARD
      if (stageselect)
        cd[i_max] = cd_stageselect;
#endif
    }
    sdt = 0;
  }

  if (cd[i_max] > 0) {
    threshold = max(threshold, level_max * k_threshold);
  }

  static time_t ct = 0;
  static int cc = 0;
  ct += dt;
  cc += 1;

#ifdef HAS_BUTTONS
  static int bi = 3;
  pinMode(bi+4, INPUT_PULLUP);
  bi = ((bi+1)&3);
  pinMode(bi+4, OUTPUT);
  digitalWrite(bi+4, LOW);

  int state;
  int* bs = button_state + (bi << 2);
  int* bc = button_cd + (bi << 2);
  for (int i = 0; i < 4; ++i) {
    state = (digitalRead(i) == LOW);
    if (bc[i] != 0) {
      bc[i] -= ct;
      if (bc[i] < 0) bc[i] = 0;
    }
    if (state != bs[i] && bc[i] == 0) {
      bs[i] = state;
      bc[i] = 15000;
#ifdef ENABLE_KEYBOARD
      if (state) {
        Keyboard.press(button_key[(bi << 2) + i]);
      } else {
        Keyboard.release(button_key[(bi << 2) + i]);
      }
#endif
    }
#ifdef ENABLE_NS_JOYSTICK
    Joystick.Button |= (bs[i] ? button[(bi << 2) + i] : SWITCH_BTN_NONE);
#endif
  }
#endif

#ifdef ENABLE_NS_JOYSTICK
  if (ct > 32000 || (ct > 8000 && (down_count[0] || down_count[1] || down_count[2] || down_count[3]))) {
    for (int i = 0; i < 4; ++i) {
      bool state = (down_count[i] & 1);
      Joystick.Button |= (state ? sensor_button[i] : SWITCH_BTN_NONE);
      down_count[i] -= !!down_count[i];
      digitalWrite(led_pin[i], state ? LOW : HIGH);
    }
#ifdef HAS_BUTTONS
    state = 0;
    for (int i = 0; i < 4; ++i) {
      state |= (button_state[i] ? 1 << i : 0);
    }
    Joystick.HAT = hat_mapping[state];
#endif
    Joystick.sendState();
    Joystick.Button = SWITCH_BTN_NONE;
#ifdef DEBUG_TIME
    if (cc > 0)
      Serial.println((float)ct/cc);
#endif
    ct = 0;
    cc = 0;
  }
#endif

#ifdef DEBUG_OUTPUT
  static bool printing = false;
#ifdef DEBUG_OUTPUT_LIVE
  if (true)
#else
  if (printing || (threshold > 10))
#endif
  {
    printing = true;
    Serial.print(level[0], 1);
    Serial.print("\t");
    Serial.print(level[1], 1);
    Serial.print("\t");
    Serial.print(level[2], 1);
    Serial.print("\t");
    Serial.print(level[3], 1);
    Serial.print("\t| ");
    Serial.print(cd[0] == 0 ? "  " : down[0] ? "# " : "* ");
    Serial.print(cd[1] == 0 ? "  " : down[1] ? "# " : "* ");
    Serial.print(cd[2] == 0 ? "  " : down[2] ? "# " : "* ");
    Serial.print(cd[3] == 0 ? "  " : down[3] ? "# " : "* ");
    Serial.print("|\t");
    Serial.print(threshold, 1);
    Serial.println();
    if(threshold <= 5){
      Serial.println();
      printing = false;
    }
  }
#endif

  level[si] = new_level;
  si = key_next[si];

  long ddt = 300 - (micros() - t0);
  if(ddt > 3) delayMicroseconds(ddt);

}

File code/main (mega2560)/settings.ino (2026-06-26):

#include "U8glib.h"
#include "JoystickButton.h"
#include "bitmaps.h"
#include "EEPROM.h"

extern U8GLIB_SSD1306_128X64 u8g;
extern JoyButton joystick;
extern int current_screen;

#define SW_PIN 8

#define EEPROM_THRESH_ADDR  0
#define EEPROM_SENS0_ADDR   1
#define EEPROM_SENS1_ADDR   2
#define EEPROM_SENS2_ADDR   3
#define EEPROM_SENS3_ADDR   4

int threshold_value = (EEPROM.read(EEPROM_THRESH_ADDR) == 255) ? 15 : EEPROM.read(EEPROM_THRESH_ADDR);

int sens_val[4] = {
  (EEPROM.read(EEPROM_SENS0_ADDR) == 255) ? 10 : EEPROM.read(EEPROM_SENS0_ADDR),
  (EEPROM.read(EEPROM_SENS1_ADDR) == 255) ? 10 : EEPROM.read(EEPROM_SENS1_ADDR),
  (EEPROM.read(EEPROM_SENS2_ADDR) == 255) ? 10 : EEPROM.read(EEPROM_SENS2_ADDR),
  (EEPROM.read(EEPROM_SENS3_ADDR) == 255) ? 10 : EEPROM.read(EEPROM_SENS3_ADDR)
};

int settings_pos = 0;
#define SETTINGS_COUNT 6

bool showSavedPopup = false;
unsigned long popupStartTime = 0;

unsigned long lastInputTime = 0;
#define INPUT_DEBOUNCE_MS 200

void sendSettingsToController() {

  Serial1.write('T');
  Serial1.write((byte)threshold_value);

  for (int i = 0; i < 4; i++) {
    Serial1.write('W');
    Serial1.write((byte)i);
    Serial1.write((byte)sens_val[i]);
  }
}

void settingsMenu() {

    joystick.update();
    int x = joystick.readX();
    int y = joystick.readY();

    if (showSavedPopup) {
        if (millis() - popupStartTime > 700) {
            showSavedPopup = false;
            current_screen = 0;
        }
        return;
    }

    if (millis() - lastInputTime < INPUT_DEBOUNCE_MS) return;

    if (y >= 700) {
        settings_pos--;
        if (settings_pos < 0) settings_pos = 0;
        lastInputTime = millis();
    }
    else if (y <= 300) {
        settings_pos++;
        if (settings_pos >= SETTINGS_COUNT) settings_pos = SETTINGS_COUNT - 1;
        lastInputTime = millis();
    }

    if (settings_pos == 0) {
        if (x >= 700) { threshold_value++; lastInputTime = millis(); }
        if (x <= 300) { threshold_value--; lastInputTime = millis(); }
        if (threshold_value < 1) threshold_value = 1;
        if (threshold_value > 255) threshold_value = 255;
    }

    if (settings_pos >= 1 && settings_pos <= 4) {
        int idx = settings_pos - 1;
        if (x >= 700) { sens_val[idx]++; lastInputTime = millis(); }
        if (x <= 300) { sens_val[idx]--; lastInputTime = millis(); }
        if (sens_val[idx] < 1)  sens_val[idx] = 1;
        if (sens_val[idx] > 50) sens_val[idx] = 50;
    }

    if (settings_pos == 5) {
        if (digitalRead(SW_PIN) == LOW) {
            EEPROM.update(EEPROM_THRESH_ADDR, (byte)threshold_value);
            EEPROM.update(EEPROM_SENS0_ADDR, (byte)sens_val[0]);
            EEPROM.update(EEPROM_SENS1_ADDR, (byte)sens_val[1]);
            EEPROM.update(EEPROM_SENS2_ADDR, (byte)sens_val[2]);
            EEPROM.update(EEPROM_SENS3_ADDR, (byte)sens_val[3]);

            sendSettingsToController();

            showSavedPopup = true;
            popupStartTime = millis();
        }
    }
}

void drawSettingsMenu() {

    settingsMenu();

    if (showSavedPopup) {
        u8g.firstPage();
        do {
            u8g.setFont(u8g_font_6x10);
            u8g.drawStr(30, 32, "Saved + Sent!");
        } while (u8g.nextPage());
        return;
    }

    u8g.firstPage();
    do {

        if (settings_pos == 0) u8g.drawBitmapP(0, 0,  128/8, 10, bitmap_item_sel_outline);
        if (settings_pos == 1) u8g.drawBitmapP(0, 10, 128/8, 10, bitmap_item_sel_outline);
        if (settings_pos == 2) u8g.drawBitmapP(0, 20, 128/8, 10, bitmap_item_sel_outline);
        if (settings_pos == 3) u8g.drawBitmapP(0, 30, 128/8, 10, bitmap_item_sel_outline);
        if (settings_pos == 4) u8g.drawBitmapP(0, 40, 128/8, 10, bitmap_item_sel_outline);
        if (settings_pos == 5) u8g.drawBitmapP(0, 54, 128/8, 10, bitmap_item_sel_outline);

        u8g.setFont(u8g_font_6x10);

        u8g.drawStr(2, 9, "Threshold");
        u8g.drawStr(90, 9, String(threshold_value).c_str());

        char buf[6];
        const char* labels[4] = {"Sens L", "Sens R", "Sens DL", "Sens DR"};
        for (int i = 0; i < 4; i++) {
            u8g.drawStr(2, 9 + (i+1)*10, labels[i]);

            sprintf(buf, "%d.%d", sens_val[i]/10, sens_val[i]%10);
            u8g.drawStr(90, 9 + (i+1)*10, buf);
        }

        u8g.drawStr(2, 63, "Save + Back");

    } while (u8g.nextPage());
}

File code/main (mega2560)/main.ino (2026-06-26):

#include "bitmaps.h"
#include "U8glib.h"
#include "JoystickButton.h"

U8GLIB_SSD1306_128X64 u8g(U8G_I2C_OPT_DEV_0 | U8G_I2C_OPT_NO_ACK | U8G_I2C_OPT_FAST);

extern int item_selected;
extern const int NUM_ITEMS;
extern int current_screen;
int current_screen=0;
#define VRX_PIN A1
#define VRY_PIN A0
#define SW_PIN 8

JoyButton joystick(VRX_PIN, VRY_PIN, SW_PIN, NUM_ITEMS);

void setup() {
  delay(300);
pinMode(11, OUTPUT);
digitalWrite(11, HIGH);
pinMode(10, OUTPUT);
digitalWrite(10, HIGH);
  u8g.setColorIndex(1);
  Serial.begin(9600);
  Serial1.begin(9600);
  joystick.setup();
  startupAnim();
}

void loop() {

  joystick.update();

  item_selected = joystick.ItemSelected();
  current_screen = joystick.CurrentScreen();

  u8g.firstPage();
  do {

    if (current_screen == 0) {
      itemsMenu();
      drawMenu();
    }
    else if (current_screen == 1) {
      drawControllerMenu();
    }
    else if (current_screen == 2) {
      drawSettingsMenu();
    }

  } while (u8g.nextPage());
}

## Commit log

2026-06-20 Rename bottom plate.step to CAD/bottom plate.step
    [bottom plate.step]
2026-06-20 Rename bottom plate.stl to CAD/bottom plate.stl
    [bottom plate.stl]
2026-06-20 Rename fully assembly.stl to CAD/fully assembly.stl
    [fully assembly.stl]
2026-06-20 Rename CAD/bottom plate.step to CAD/bottom/bottom plate.step
    [bottom plate.step]
2026-06-20 Rename CAD/bottom plate.stl to CAD/bottom/bottom plate.stl
    [bottom plate.stl]
2026-06-20 Rename support leg.step to bottom/support leg.step
    [support leg.step]
2026-06-20 Rename support leg.stl to bottom/support leg.stl
    [support leg.stl]
2026-06-20 Rename bottom/support leg.step to CAD/bottom/support leg.step
    [support leg.step]
2026-06-20 Rename bottom/support leg.stl to CAD/bottom/support leg.stl
    [support leg.stl]
2026-06-20 Rename top plate inner circle half.step to CAD/top/top plate inner circle half.step
    [top plate inner circle half.step]
2026-06-20 Rename top plate inner circle half.stl to CAD/top/top plate inner circle half.stl
    [top plate inner circle half.stl]
2026-06-20 Rename top plate outer ring half.step to CAD/top/top plate outer ring half.step
    [top plate outer ring half.step]
2026-06-20 Rename top plate outer ring half.stl to CAD/top/top plate outer ring half.stl
    [top plate outer ring half.stl]
2026-06-24 Rename tntebox.kicad_pro to Prototype schematic.kicad_pro
2026-06-25 Add link to large STEP file on Google Drive
    Added a link to a large STEP file hosted on Google Drive.
    [fully assembly.step]
2026-06-25 Update README with prototype video and image
    Added a video demonstration of the prototype and an image.
2026-06-25 Create full assembly part credits
2026-06-26 Add bottom plate CAD file
    [bottom plate.step]
2026-06-26 Rename bottom plate.stl to CADbottom plate.stl
    [CADbottom plate.stl]
2026-06-26 Rename drum/bottom/CADbottom plate.stl to CAD/drum/bottom/bottom plate.stl
    [bottom plate.stl]
2026-06-26 Rename CAD/fully assembly .stl to CAD/drum/fully assembly .stl
    [fully assembly .stl]
2026-06-26 Rename CAD/fully assembly.step to CAD/drum/fully assembly.step
    [fully assembly.step]
2026-06-26 Rename CAD/top/top plate inner circle half.step to CAD/drum/top/top plate inner circle half.step
    [top plate inner circle half.step]
2026-06-26 Rename CAD/top/top plate inner circle half.stl to CAD/drum/top/top plate inner circle half.stl
    [top plate inner circle half.stl]
2026-06-26 Rename CAD/top/top plate outer ring half.step to CAD/drum/top/top plate outer ring half.step
    [top plate outer ring half.step]
2026-06-26 Rename CAD/top/top plate outer ring half.stl to CAD/drum/top/top plate outer ring half.stl
    [top plate outer ring half.stl]
2026-06-26 Rename CAD/bottom/support leg.step to CAD/drum/bottom/support leg.step
    [support leg.step]
2026-06-26 Rename CAD/bottom/support leg.stl to CAD/drum/bottom/support leg.stl
    [support leg.stl]
2026-06-26 Rename CAD/assemblyparts/corner brace.step to CAD/drum/assemblyparts/corner brace.step
    [corner brace.step]
2026-06-26 Rename CAD/assemblyparts/corner brace.stl to CAD/drum/assemblyparts/corner brace.stl
    [corner brace.stl]
2026-06-26 Rename CAD/assemblyparts/long bolt.step to CAD/drum/assemblyparts/long bolt.step
    [long bolt.step]
2026-06-26 Rename CAD/assemblyparts/long bolt.stl to CAD/drum/assemblyparts/long bolt.stl
    [long bolt.stl]
2026-06-26 Add rubber insert STEP file to drum assembly parts
    [rubber insert.step]
2026-06-26 Rename rubber insert.stl to CADrubber insert.stl
    [CADrubber insert.stl]
2026-06-26 Rename drum/assemblyparts/CADrubber insert.stl to CAD/drum/assemblyparts/rubber insert.stl
    [rubber insert.stl]
2026-06-26 Update BOM.csv with new items and links
    [BOM.csv]
2026-06-26 Rename Prototype schematic.kicad_pro to schematic.kicad_pro
2026-06-26 Add case assembly image part credits
2026-06-26 Rename case assembly image part credits to full case assembly part credits
2026-06-26 Rename CAD/full case assembly part credits to CAD/case/full case assembly part credits
2026-06-26 Rename full case assembly part credits to full case assembly part credits
2026-06-26 Update BOM.csv with new items and prices
    Updated BOM.csv to reflect new items and prices, including various components and tools for the project.
    [BOM.csv]
2026-06-26 Add code flashing instructions for Arduino Leonardo
    Added instructions for flashing code to Arduino Leonardo.
2026-06-26 Create NOTE: ALL CAD IS MADE IN TINKERCAD
